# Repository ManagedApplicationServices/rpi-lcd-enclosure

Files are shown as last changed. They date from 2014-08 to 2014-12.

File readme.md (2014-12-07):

#RaspberryPI + LCD enclosure

This project contains the top and bottom parts of the enclosure housing:

1. [Raspberry PI Model B+](http://www.raspberrypi.org/product/model-b-plus/)
1. [LCD HDMI 5.6 inch](http://www.adafruit.com/products/1666)

Resources for various mechanical drawings:

1. [RPi B+](http://www.element14.com/community/servlet/JiveServlet/previewBody/68118-102-2-295701/RPI-BPLUS-V1_2-MECHDRAWING.pdf)
- [Micro SD Card](http://en.wikipedia.org/wiki/Secure_Digital#mediaviewer/File:SD_Cards.svg) `12mm by 15mm`
- [micro USB](http://upload.wikimedia.org/wikipedia/commons/thumb/3/3c/USB_Micro-B_plug_size.svg/179px-USB_Micro-B_plug_size.svg.png) `6.85mm by 1.8mm`
- [Ethernet port](http://connect.iobridge.com/wp-content/uploads/2012/11/iota-Ethernet-Physical-Dimensions.jpg)
- [LCD PCB (page 5)](http://www.adafruit.com/datasheets/PCB800099.pdf) and [LCD controls](http://www.adafruit.com/datasheets/PCB800023%20Keyboard.pdf)
- [HDMI](http://www.extron.com/product/img/specs/MDC_1.5-6_HDMI_cable_dimen_w-out_ferrites.gif)

Types of file included:

- `*.123dx` are 3D editable design file with [123D Design](http://www.123dapp.com/design)
- `*.stl` files are 3D design files

File explanations:

1. `base-bottom.123dx` - 2D projection of the bottom enclosure before 3D extrusion

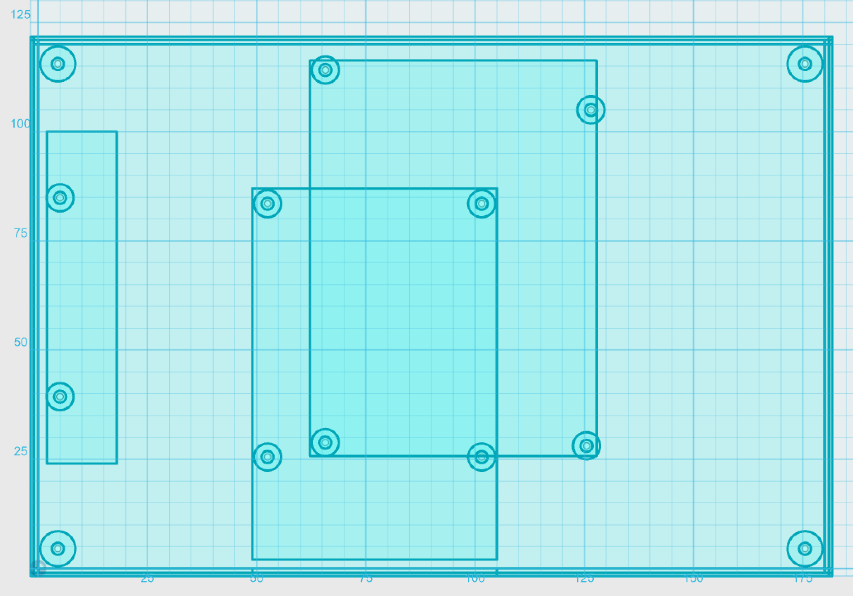
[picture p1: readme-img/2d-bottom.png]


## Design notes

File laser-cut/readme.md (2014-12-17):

#laser cutting

All designs were created using [InkScape](https://www.inkscape.org/en/) and exported to `*.svg` and `*.dxf` formats.

Some concepts include:

1. dog bone corner

	
	
- finger slots
- friction-fit

Main drawings are:

1. **inital unmerged** contains the design of 6 sides of the enclosure before any merge or substraction

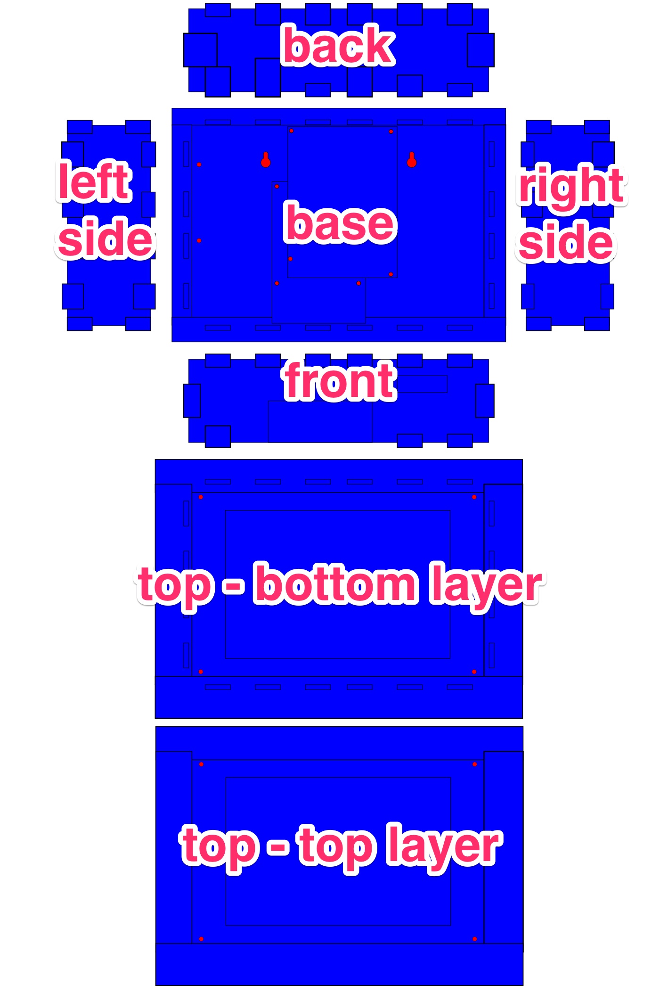
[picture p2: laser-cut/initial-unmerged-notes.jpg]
	
- **3mm** has the designs for base and 4 sides of the enclosure

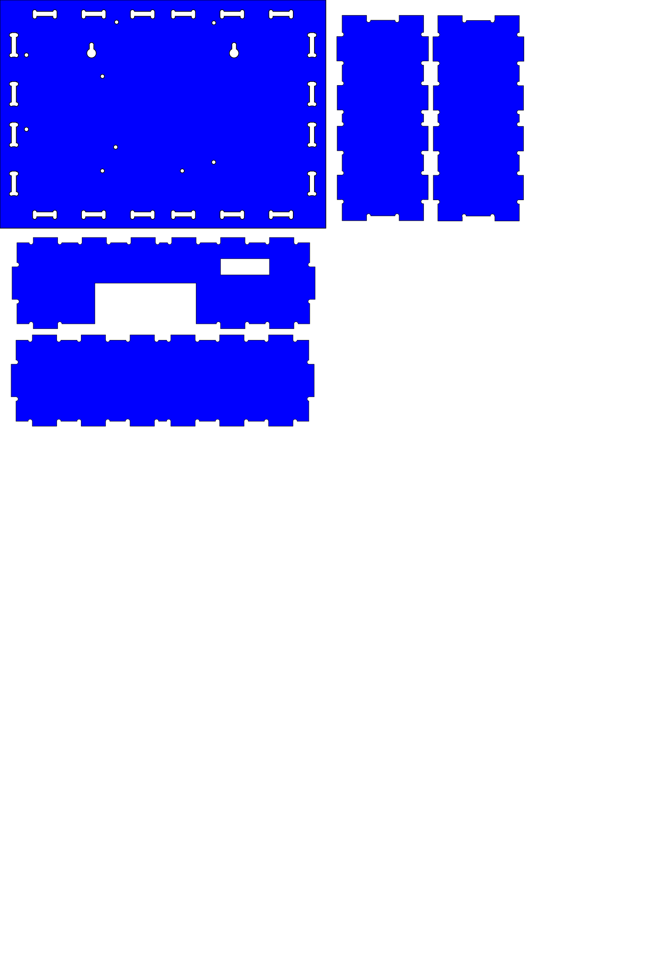
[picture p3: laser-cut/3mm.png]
	
- **2mm** has the designs for the top 2 acrylic pieces holding the LCD

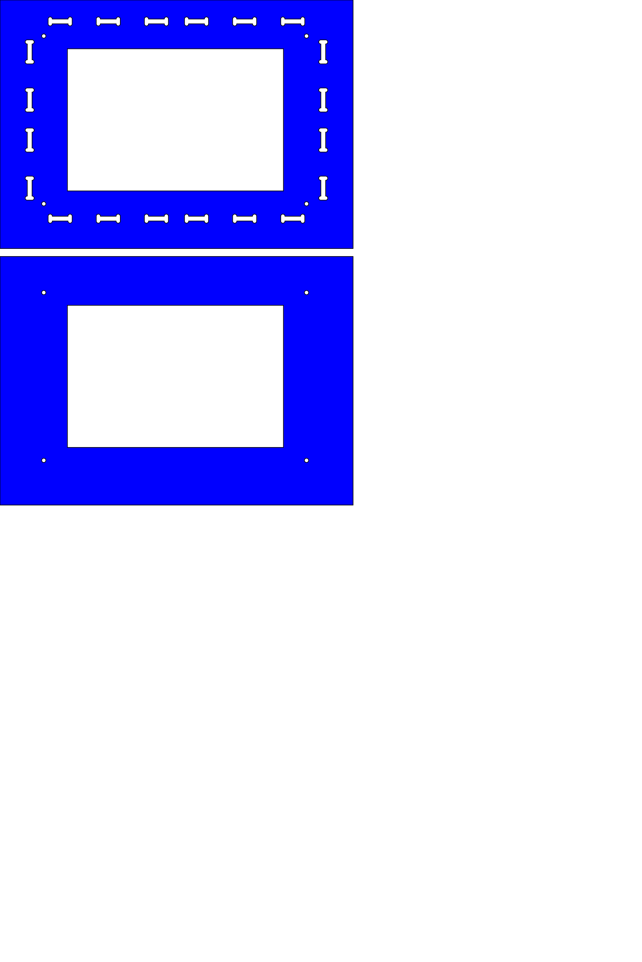
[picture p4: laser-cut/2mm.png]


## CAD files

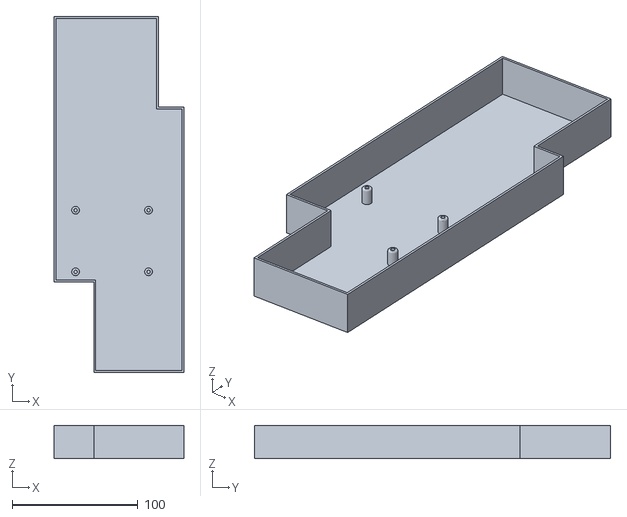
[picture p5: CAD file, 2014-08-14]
3d-bottom.stl
103.0 x 283.0 x 26.5

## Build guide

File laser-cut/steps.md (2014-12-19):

##In Adobe Illustrator CS6

1. keep only outlines of the shapes
- save as `*.ai` for each individual piece
	- uncheck all options in the export window
- copy to an SD Card

##In Autolaser

1. File > Import > file `*.ai` each of the individual pieces
- arrange all the pieces with some gap/tolerence among each other
- if the lines after import are corrupted, redo in AI and import again
- cut small pieces first - under `Work` tab
- Choose `60W` for power
- Check that the back door is sealed up so that fumes don't get into the lab

##Laser cutter

1. turn on the laser cutter
- adjust the origin by pressing the up/down, left/right buttons
- press `Origin`
- Click `Search` in Autolaser and dropdown to `COM{X}` to detect acrylic, else save and reopen the autolaser file `*.wcvr` extension
- Click `Start` to begin laser cutting

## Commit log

2014-08-14 rpi base with 4 mounting holes
2014-08-14 rpi mount holes are made .5mm smaller for grip
2014-08-14 added micro USB power
2014-08-14 added LCD control board and LCD PCB board
2014-08-14 exported to stl for base
2014-08-14 removed stl file
2014-08-14 added mounting holes for LCD main PCB
2014-08-14 mounting holes are expanding for extruding in 3d
2014-08-14 completed 2D base bottom before extrusion
2014-08-14 rpi 3d with mounting holes
    [3d-bottom.stl]
2014-08-14 3d mounting holes completed for LCD PCB, controls and RPi
2014-08-14 explorted stl format for 3d bottom
2014-08-14 ethernet port slot created
2014-08-14 USB1 RPi slot created
2014-08-14 added power slots for rpi and LCD
2014-12-07 3d bottom case
2014-12-07 deleted previous bottom case file
2014-12-07 increase bottom box screw hole to accomodate 5.3mm screw head
2014-12-07 new exported stl file based on bottom box screw head
2014-12-08 fix bottom casing mounting hole
2014-12-09 fix case mounting to flat heads
2014-12-16 feature: laser cut designs for 3mm and 2mm acrylic
2014-12-16 feature: add dxf file formats
    [2mm.dxf, 3mm.dxf, initial-unmerged.dxf]
2014-12-16 feature: readme for laser cut files
2014-12-17 refactor: add dog bone corners
    [2mm.dxf, 3mm.dxf, initial-unmerged.dxf]
2014-12-17 refactor: add more formats
    [initial-unmerged.dxf]
2014-12-17 refactor: add 2mm svg format
2014-12-17 refactor: add 3mm svg format
2014-12-17 refactor: fix dog bone collars
    [2mm.dxf, 3mm.dxf, initial-unmerged.dxf]
2014-12-17 refactor: add dog bone corners properly with various formats
    [2mm.dxf, 3mm.dxf]
2014-12-18 refactor: use AI to make svg and ai formats
    [2mm.dxf, 3mm.dxf]
2014-12-19 docs: add steps for laser cutting with the machine
